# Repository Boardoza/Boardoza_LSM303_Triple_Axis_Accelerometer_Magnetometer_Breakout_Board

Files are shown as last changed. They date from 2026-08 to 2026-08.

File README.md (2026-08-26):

# Boardoza LSM303 Triple Axis Accelerometer & Magnetometer Breakout Board

The **Boardoza LSM303 Breakout Board** is a compact and ultra-low-power motion sensing solution featuring the **STMicroelectronics LSM303AGR** 6-axis e-compass sensor. It combines a **3-axis digital accelerometer** and a **3-axis digital magnetometer** in a single package, enabling accurate motion tracking, orientation sensing, and tilt-compensated compass applications.

Designed for seamless integration with both modern and legacy development platforms, the board includes a **TXS0104 bi-directional logic level shifter**, allowing direct compatibility with both **3.3V and 5V microcontrollers** such as ESP32, STM32, Raspberry Pi Pico, and Arduino Uno. With support for high-speed I<sup>2</sup>C communication and advanced interrupt functionality, this board is ideal for **robotics, wearable devices, navigation systems, drones, IoT applications, and smart motion-based projects**.

| Front Side | Back Side |
|:---:|:---:|
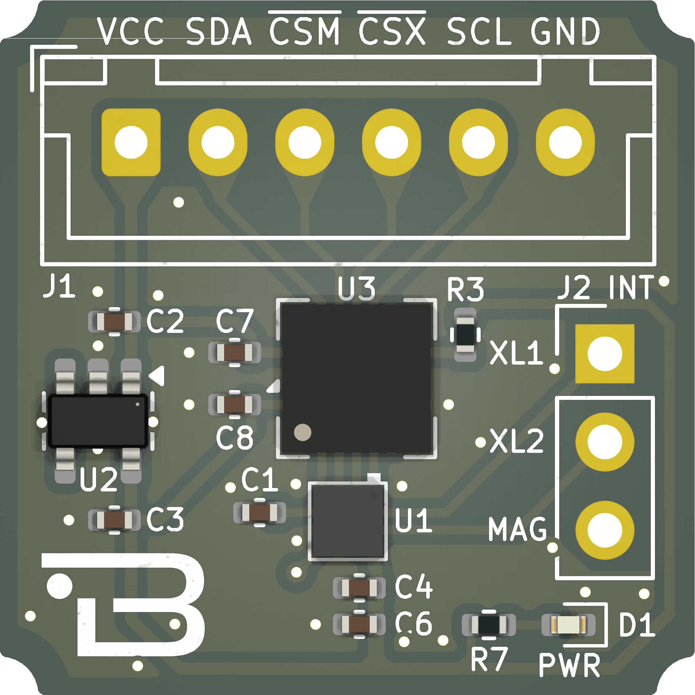
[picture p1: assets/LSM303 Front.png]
LSM303AGR Front
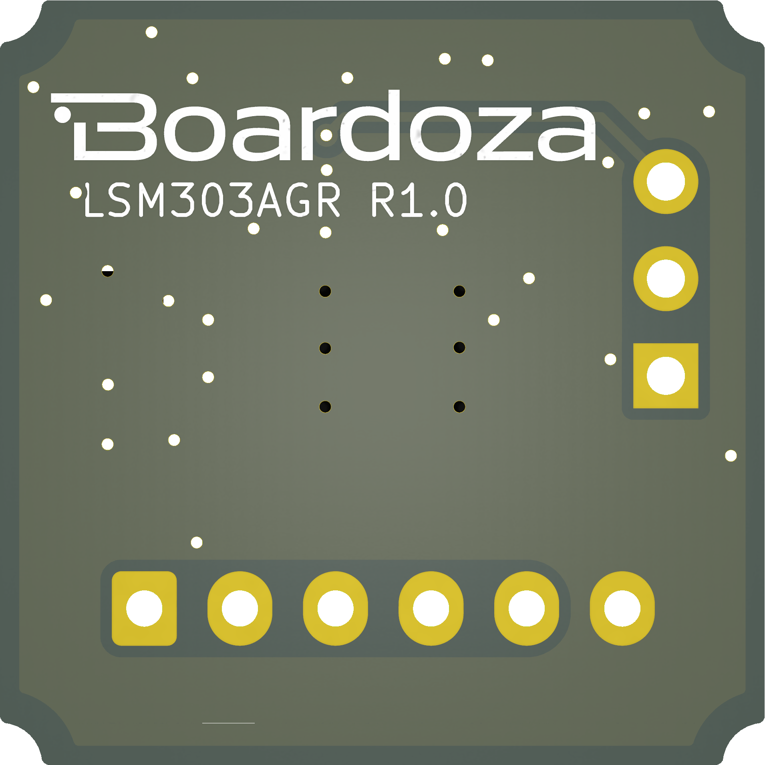
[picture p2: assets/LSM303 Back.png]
LSM303AGR Back
|  |  |

---

## Key Features

- **Integrated 6-Axis Motion Sensor:** Combines a 3-axis accelerometer and 3-axis magnetometer in a single compact module.
- **True E-Compass Functionality:** Enables accurate heading and orientation measurements using tilt compensation.
- **Wide Logic Compatibility:** Built-in TXS0104 level shifter supports both 3.3V and 5V systems.
- **High-Speed I<sup>2</sup>C Communication:** Supports Standard, Fast Mode (400kHz), and Fast Mode Plus (1MHz).
- **Ultra-Low Power Operation:** Optimized for battery-powered and energy-efficient embedded systems.
- **Programmable Interrupts:** Supports free-fall detection, orientation sensing, magnetic threshold detection, and motion events.

---

## Technical Specifications

**Model:** LSM303AGRTR  
**Manufacturer:** Boardoza    
**Manufacturer IC:** STMicroelectronics   
**Sensor Type:** 3-Axis Accelerometer + 3-Axis Magnetometer  
**Input Voltage:** 3.3 VDC - 5V DC  
**Voltage Logic Compatibility:** 3.3V / 5V (via TXS0104 Level Shifter)  
**Communication Interface:** I<sup>2</sup>C  / SPI  
**I<sup>2</sup>C Speed:** Standard Mode (100kHz), Fast Mode (400kHz), Fast Mode Plus (1MHz)   
**Accelerometer Full Scale Range:** ±2g / ±4g / ±8g / ±16g  
**Magnetic Field Range:** ±50 gauss  
**Accelerometer Resolution:** 12-bit  
**Magnetometer Resolution:** 16-bit  
**Functions:** Motion Detection, Orientation Sensing, Digital Compass, Tilt Compensation  
**Interrupt Features:** Free-fall, 6D/4D orientation, magnetic threshold interrupt  
**Operating Temperature:** -40°C to +85°C  
**Board Dimensions:** 20mm x 20mm  

---

## Board Pinout

### ( J1 ) Main Communication Connector

| Pin Number | Pin Name | Description |
|:---:|:---:|---|
| 1 | VCC | Voltage Supply Input |
| 2 | SDA / SDI / SDO | I<sup>2</sup>C Data / SPI Data Input / 3-wire SPI Data Output |
| 3 | /CS_MAG | Active-Low Magnetometer SPI Chip Select |
| 4 | /CS_XL | Active-Low Accelerometer SPI Chip Select |
| 5 | SCL / SPC | I<sup>2</sup>C Clock / SPI Clock |
| 6 | GND | Ground |

### ( J2 ) Interrupt Connector

| Pin Number | Pin Name | Description |
|:---:|:---:|---|
| 1 | XL1 | Accelerometer Interrupt Output 1 (3.3V Logic) |
| 2 | XL2 | Accelerometer Interrupt Output 2 (3.3V Logic) |
| 3 | MAG | Magnetometer Interrupt / Data Ready Output (3.3V Logic) |

---

## Board Dimensions

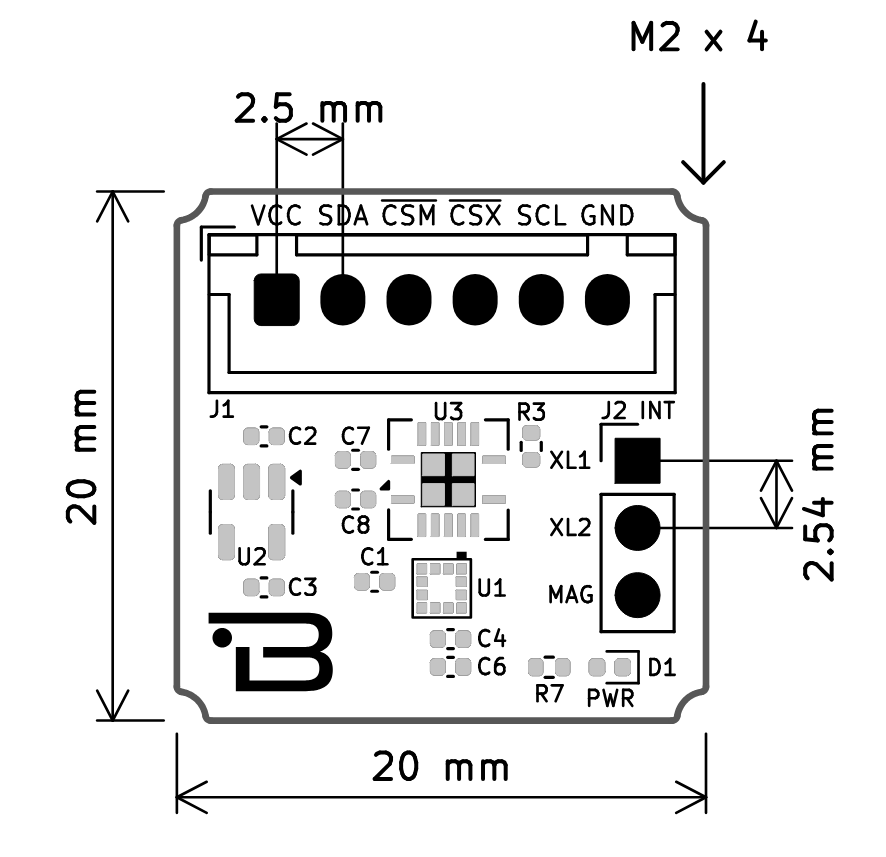
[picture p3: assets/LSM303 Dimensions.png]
LSM303AGRTR Dimensions


---

## Step Files

[Boardoza LSM303AGRTR.step](./assets/LSM303%20Step.step)

---

## Datasheet

[LSM303AGR Datasheet.pdf](./assets/LSM303%20Datasheet.pdf)

---

## Version History

- V1.0.0 - Initial Release

---

## Support

- If you have any questions or need support, please contact support@boardoza.com

---

## **License**

This repository contains both hardware and software components:

### **Hardware Design**

[][cc-by-sa]

All hardware design files are licensed under [Creative Commons Attribution-ShareAlike 4.0 International License][cc-by-sa].

[cc-by-sa]: http://creativecommons.org/licenses/by-sa/4.0/
[cc-by-sa-shield]: https://img.shields.io/badge/License-CC%20BY--SA%204.0-lightgrey.svg

### **Software/Firmware**

[][bsd]

All software and firmware are licensed under [BSD 3-Clause License][bsd].

[bsd]: https://opensource.org/licenses/BSD-3-Clause
[bsd-shield]: https://img.shields.io/badge/License-BSD%203--Clause-blue.svg

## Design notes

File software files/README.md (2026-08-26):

# Boardoza LSM303AGR Library





Ultra-compact 3D accelerometer and 3D magnetometer (eCompass) library for the STMicroelectronics **LSM303AGR** sensor.

## 🚀 Competitive Advantage

**First Arduino library with FULL I2C + SPI support for LSM303AGR!**

Unlike other LSM303AGR libraries that only support I2C, Boardoza provides:
- ✅ **Dual Protocol Support**: Choose I2C or SPI based on your application needs
- ✅ **25x Faster Data Transfer**: SPI operates at up to 10 MHz vs 400 kHz I2C Fast Mode
- ✅ **Unified API**: Same functions work regardless of I2C or SPI initialization
- ✅ **Flexible Integration**: Use I2C when pin count is limited, SPI when speed matters

## Features

- 🔄 **Dual Communication Protocol**: I2C and SPI (unique in Arduino ecosystem)
- 📊 **3-Axis Accelerometer**: ±2g to ±16g selectable range, 1-400Hz output data rate
- 🧭 **3-Axis Magnetometer**: ±50 gauss range, 10-100Hz output data rate
- 🌡️ **Temperature Sensor**: Integrated temperature measurement
- ⚡ **Power Management**: Low-power and high-resolution modes
- 🔍 **Built-in Self-Test**: Hardware verification for both accelerometer and magnetometer
- 🎯 **Calibration Support**: Example code for hard-iron and soft-iron compensation
- 📚 **4 Complete Examples**: I2C, SPI, calibration, and self-test

## Hardware Specifications

| Parameter | Value |
|---|---|
| Operating Voltage | 1.71V to 3.6V |
| Operating Temperature | -40°C to +85°C |
| Accelerometer Range | ±2g, ±4g, ±8g, ±16g (user-selectable) |
| Magnetometer Range | ±50 gauss |
| Accelerometer ODR | 1Hz to 400Hz |
| Magnetometer ODR | 10Hz to 100Hz |
| I2C Addresses | 0x19 (Accel), 0x1E (Mag) |
| SPI Mode | Mode 3 (CPOL=1, CPHA=1) |
| SPI Clock Speed | 1 MHz to 10 MHz |

## Installation

### Arduino IDE
1. Download this repository as ZIP
2. In Arduino IDE: **Sketch** → **Include Library** → **Add .ZIP Library**
3. Select the downloaded ZIP file
4. Restart Arduino IDE

### PlatformIO
```ini
lib_deps = 
    boardoza/Boardoza LSM303AGR@^1.0.0
```

## Quick Start

### I2C Mode (Simple)
```cpp
#include <Wire.h>
#include <LSM303AGR.h>

LSM303AGR sensor;

void setup() {
  Serial.begin(115200);
  Wire.begin();
  
  if (!sensor.begin()) {
    Serial.println("Sensor not found!");
    while (1);
  }
  
  sensor.setAccelRange(2);   // ±2g
  sensor.setMagMode(MAG_MODE_CONTINUOUS);
}

void loop() {
  float ax, ay, az, mx, my, mz;
  
  sensor.readAccel(ax, ay, az);  // m/s²
  sensor.readMag(mx, my, mz);    // µT
  
  Serial.print("Accel: "); 
  Serial.print(ax); Serial.print(", ");
  Serial.print(ay); Serial.print(", ");
  Serial.println(az);
  
  delay(100);
}
```

### SPI Mode (High-Speed)
```cpp
#include <SPI.h>
#include <LSM303AGR.h>

#define CS_ACCEL 10
#define CS_MAG   9

LSM303AGR sensor;

void setup() {
  Serial.begin(115200);
  SPI.begin();
  
  if (!sensor.beginSPI(CS_ACCEL, CS_MAG)) {
    Serial.println("Sensor not found!");
    while (1);
  }
  
  sensor.setSPIClockSpeed(10000000);  // 10 MHz for max speed
  sensor.setAccelRange(2);
  sensor.setAccelDataRate(400);       // 400Hz for high-speed logging
  sensor.setMagMode(MAG_MODE_CONTINUOUS);
}

void loop() {
  float ax, ay, az, mx, my, mz;
  
  if (sensor.isAccelDataReady()) {
    sensor.readAccel(ax, ay, az);
    // Process at 400Hz!
  }
  
  delay(10);
}
```

## Wiring

### I2C Wiring
```
LSM303AGR    Arduino Uno/Nano    Arduino Mega    ESP32
──────────────────────────────────────────────────────────
VDD          3.3V                3.3V            3.3V
GND          GND                 GND             GND
SDA          A4                  20              21 (GPIO21)
SCL          A5                  21              22 (GPIO22)
CS_ACCEL     3.3V (tied high)    3.3V            3.3V
CS_MAG       3.3V (tied high)    3.3V            3.3V
```

**Note**: I2C requires pull-up resistors (4.7kΩ recommended) on SDA and SCL lines.

### SPI Wiring
```
LSM303AGR    Arduino Uno/Nano    Arduino Mega    ESP32
──────────────────────────────────────────────────────────
VDD          3.3V                3.3V            3.3V
GND          GND                 GND             GND
MOSI         11                  51              23 (GPIO23)
MISO         12                  50              19 (GPIO19)
SCK          13                  52              18 (GPIO18)
CS_ACCEL     10 (user-defined)   10              5  (GPIO5)
CS_MAG       9  (user-defined)   9               4  (GPIO4)
SDA          N/C                 N/C             N/C
SCL          N/C                 N/C             N/C
```

**Note**: SPI requires separate chip select (CS) pins for accelerometer and magnetometer.

## I2C vs SPI Performance Comparison

| Feature | I2C | SPI |
|---|-----|-----|
| Max Clock Speed | 400 kHz (Fast Mode) | 10 MHz |
| Data Transfer Rate | ~50 KB/s | ~1.25 MB/s |
| Pin Count | 2 (SDA, SCL) | 5 (MOSI, MISO, SCK, CS_ACCEL, CS_MAG) |
| Multi-Device Bus | Yes (addressable) | No (requires separate CS pins) |
| Speed Advantage | Baseline (1x) | **25x faster** |
| Recommended Use | Low pin count, multiple sensors | High-speed logging, real-time control |

**Use I2C when:**
- Pin count is limited
- Sharing bus with other I2C devices
- Speed is not critical (<100Hz sampling)

**Use SPI when:**
- Maximum throughput is required (>100Hz)
- Real-time data logging applications
- Minimizing latency is critical
- Dedicated communication bus available

## API Reference

### Initialization
- `bool begin(TwoWire *wire = &Wire)` - Initialize in I2C mode
- `bool beginSPI(uint8_t csAccel, uint8_t csMag, SPIClass *spi = &SPI)` - Initialize in SPI mode
- `void setSPIClockSpeed(uint32_t speed)` - Set SPI clock (1-10 MHz)

### Accelerometer
- `bool setAccelRange(uint8_t range)` - Set range: 2, 4, 8, or 16 (±g)
- `bool setAccelDataRate(uint16_t rate)` - Set ODR: 1, 10, 25, 50, 100, 200, 400 (Hz)
- `bool enableAccelAxes(bool x, bool y, bool z)` - Enable/disable axes
- `bool setAccelPowerMode(LSM303AGR_PowerMode mode)` - Low-power or high-resolution
- `bool setAccelEnabled(bool enabled)` - Power up/down accelerometer
- `bool readAccel(float &x, float &y, float &z)` - Read acceleration (m/s²)
- `bool isAccelDataReady()` - Check if new data available

### Magnetometer
- `bool setMagMode(LSM303AGR_MagMode mode)` - Continuous, single-shot, or idle
- `bool setMagDataRate(uint16_t rate)` - Set ODR: 10, 20, 50, 100 (Hz)
- `bool setMagOffsetCancellation(bool enabled)` - Hard-iron compensation
- `bool readMag(float &x, float &y, float &z)` - Read magnetic field (µT)
- `bool isMagDataReady()` - Check if new data available

### Temperature
- `bool enableTemperature(bool enabled)` - Enable/disable temperature sensor
- `float readTemperature()` - Read temperature (°C, ±2°C accuracy)

### Self-Test
- `bool runAccelSelfTest()` - Verify accelerometer operation
- `bool runMagSelfTest()` - Verify magnetometer operation

### Protocol Query
- `bool isI2C()` - Check if initialized in I2C mode
- `bool isSPI()` - Check if initialized in SPI mode

## Examples

### 1. Basic_Reading_I2C
Simple I2C example reading accelerometer, magnetometer, and temperature.

### 2. Basic_Reading_SPI ⚡
High-speed SPI example demonstrating competitive advantage with 400Hz sampling.

### 3. Magnetometer_Calibration
Interactive calibration procedure for hard-iron and soft-iron compensation. Works with both I2C and SPI.

### 4. Self_Test
Hardware verification using built-in self-test features. Works with both I2C and SPI.

## Calibration

Magnetometer readings benefit from calibration to compensate for:
- **Hard-iron distortion**: Nearby ferromagnetic materials (e.g., screws, batteries)
- **Soft-iron distortion**: Induced magnetic fields from PCB traces, power circuits

Run the `Magnetometer_Calibration` example to obtain calibration coefficients. Apply in your code:

```cpp
// From calibration example
const float MAG_OFFSET_X = -12.34;
const float MAG_OFFSET_Y = 5.67;
const float MAG_OFFSET_Z = -8.90;
const float MAG_SCALE_X = 1.05;
const float MAG_SCALE_Y = 0.98;
const float MAG_SCALE_Z = 1.02;

float mx, my, mz;
sensor.readMag(mx, my, mz);

// Apply calibration
mx = (mx - MAG_OFFSET_X) * MAG_SCALE_X;
my = (my - MAG_OFFSET_Y) * MAG_SCALE_Y;
mz = (mz - MAG_OFFSET_Z) * MAG_SCALE_Z;
```

## Troubleshooting

**Sensor not detected (begin() returns false)**
- Check wiring connections
- Verify I2C addresses (0x19 for accelerometer, 0x1E for magnetometer)
- Ensure pull-up resistors on SDA/SCL (I2C mode)
- Check power supply (1.71V-3.6V)

**Erratic magnetometer readings**
- Move away from magnetic interference sources
- Run magnetometer calibration
- Enable offset cancellation: `sensor.setMagOffsetCancellation(true)`

**SPI communication failure**
- Verify CS pins are correctly connected and specified
- Check SPI mode (should be Mode 3)
- Ensure SPI clock speed is within 1-10 MHz range

**Self-test fails**
- Check for mechanical damage to sensor
- Verify electrical connections
- Try different sensor module
- Review self-test threshold criteria in example code

## License

This library is released under the MIT License. See LICENSE file for details.

## About Boardoza

Boardoza creates professional-grade Arduino libraries with a focus on:
- 🎯 **Complete Feature Coverage**: Full API implementation, not just basics
- 🚀 **Performance**: Advanced features like SPI support for maximum throughput
- 📖 **Documentation**: Comprehensive examples and clear API reference
- 🔧 **Professional Standards**: Follows industry best practices

Visit [Boardoza.com](https://boardoza.com) for more libraries and embedded solutions.

## Contributing

Contributions are welcome! Please:
1. Fork the repository
2. Create a feature branch
3. Follow the existing code style (Doxygen comments in .cpp only)
4. Test on hardware
5. Submit a pull request

## Support

- **Issues**: [GitHub Issues](https://github.com/Boardoza/Boardoza_LSM303AGR_Library/issues)
- **Email**: eray.eroglu@boardoza.com
- **Website**: [Boardoza.com](https://boardoza.com)

## Credits

Developed by Boardoza with reference to:
- STMicroelectronics LSM303AGR datasheet (DocID027765 Rev 3)
- STMicroelectronics application notes AN4602, AN4508

## Changelog

### Version 1.0.0 (Initial Release)
- ✅ Complete I2C implementation
- ✅ Complete SPI implementation (industry-first for LSM303AGR)
- ✅ Unified protocol-agnostic API
- ✅ Accelerometer with 4 ranges, 7 data rates
- ✅ Magnetometer with continuous/single-shot modes
- ✅ Temperature sensor support
- ✅ Built-in self-test routines
- ✅ 4 comprehensive examples
- ✅ Full Doxygen documentation

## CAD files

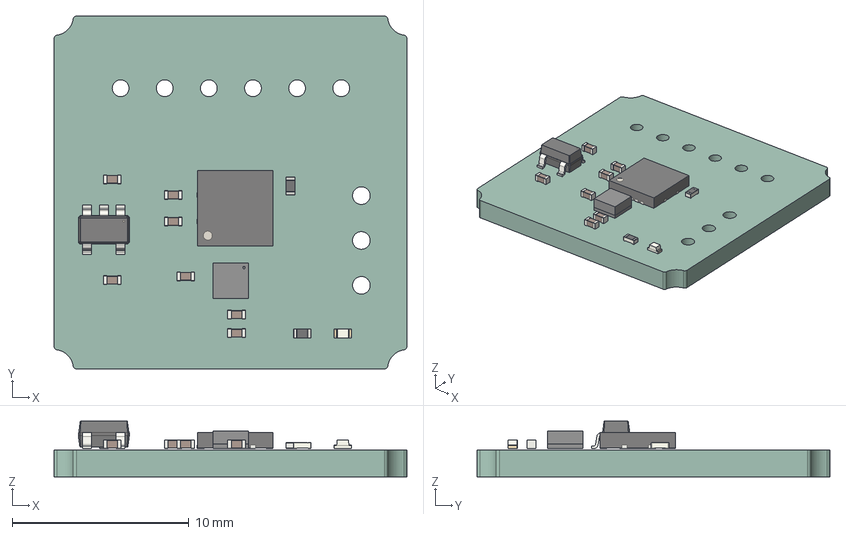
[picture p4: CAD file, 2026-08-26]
assets/LSM303 Step.step
20.0 x 20.0 x 3.15 mm
C_0402_1005Metric x 7
Texas_S-PVQFN-N14
LED_0402_1005Metric
R_0402_1005Metric x 2
kicad_embedded_3351D60FDAF86F74528C59DA770C054B
SOT-23-5
kibot_qq67svuy_PCB

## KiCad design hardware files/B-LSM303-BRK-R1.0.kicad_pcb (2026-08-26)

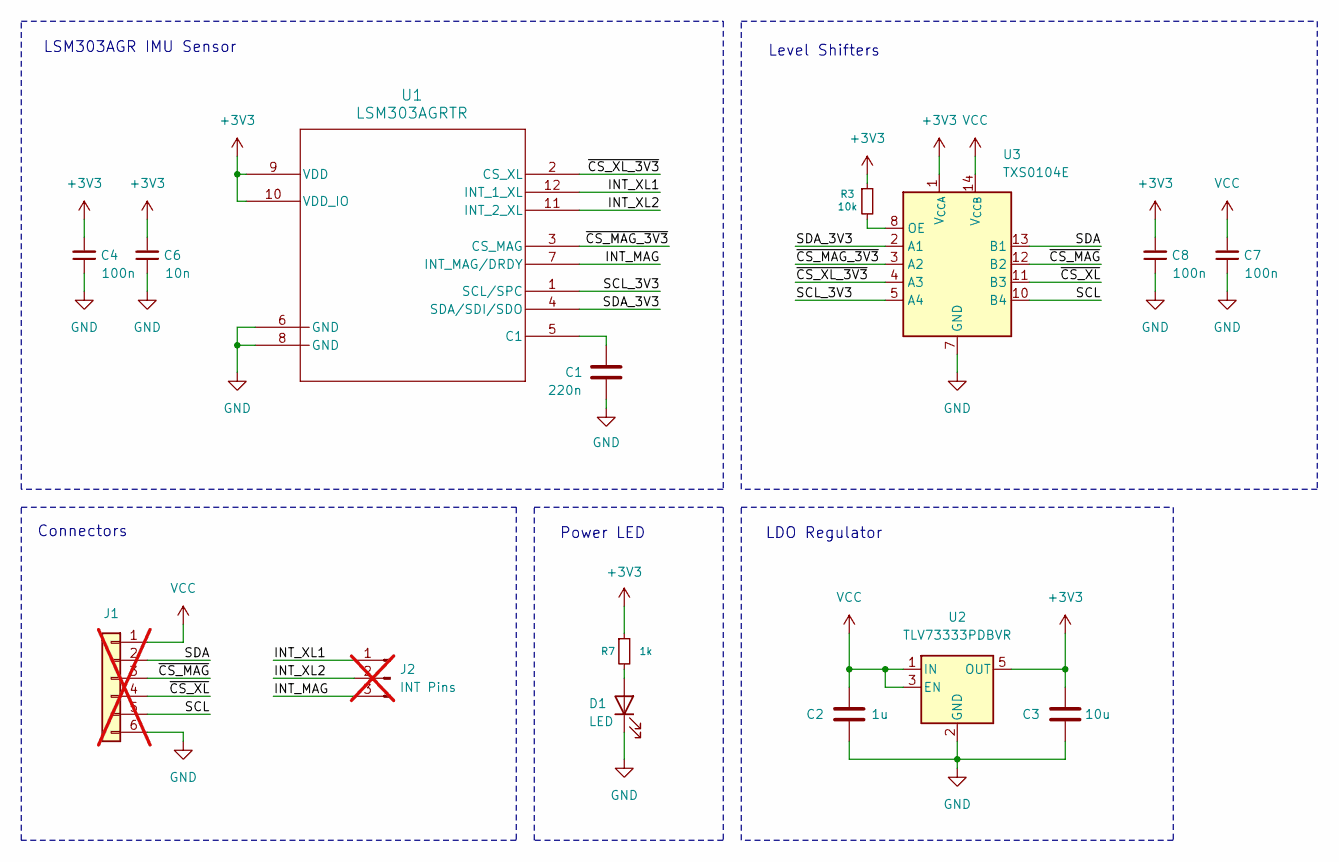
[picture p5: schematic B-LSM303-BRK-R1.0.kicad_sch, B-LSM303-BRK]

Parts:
C1: 220n; C_0402_1005Metric; MPN MCF02KTX100224
C2: 1u; C_0402_1005Metric; MPN CL05A105KO5NNNC
C3: 10u; C_0402_1005Metric; MPN CL05A106MP5NUNC
C4, C7, C8: 100n; C_0402_1005Metric; MPN CL05B104KO5NNNC
C6: 10n; C_0402_1005Metric; MPN CL05B103KA5NNNC
D1: LED; LED_0402_1005Metric; MPN 16-213SURC/S530-A3/TR8
J1: Conn_01x06; JST_XH_B6B-XH-A_1x06_P2.50mm_Vertical; MPN L-KLS1-2.50-06-SB; not fitted
J2: INT Pins; PinHeader_1x03_P2.54mm_Vertical; MPN L-KLS1-207-1-03-S; not fitted
R3: 10k; R_0402_1005Metric; MPN CRT02J6E1002
R7: 1k; R_0402_1005Metric; MPN 0402WGJ0102TCE
U1: LSM303AGRTR; SON_03AGRTR_STM; MPN LSM303AGRTR
U2: TLV73333PDBVR; SOT-23-5; MPN TLV73333PDBVR
U3: TXS0104E; Texas_S-PVQFN-N14; MPN TXS0104ERGYR

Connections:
+3V3: C3.1, C4.2, C6.2, C8.2, R3.1, R7.1, U1.9 (VDD), U1.10 (VDD_IO), U2.5 (OUT), U3.1 (V_{CCA})
/INT_MAG: J2.3, U1.7 (INT_MAG/DRDY)
/INT_XL1: J2.1, U1.12 (INT_1_XL)
/INT_XL2: J2.2, U1.11 (INT_2_XL)
/SCL: J1.5, U3.10 (B4)
/SCL_3V3: U1.1 (SCL/SPC), U3.5 (A4)
/SDA: J1.2, U3.13 (B1)
/SDA_3V3: U1.4 (SDA/SDI/SDO), U3.2 (A1)
/~CS_MAG_3V3: U1.3 (CS_MAG), U3.3 (A2)
/~CS_MAG: J1.3, U3.12 (B2)
/~CS_XL_3V3: U1.2 (CS_XL), U3.4 (A3)
/~CS_XL: J1.4, U3.11 (B3)
GND: C1.1, C2.1, C3.2, C4.1, C6.1, C7.1, C8.1, D1.1 (K), J1.6, U1.6 (GND), U1.8 (GND), U2.2 (GND), U3.7 (GND), U3.15
unnamed: D1.2 (A), R7.2
unnamed: C1.2, U1.5 (C1)
unnamed: R3.2, U3.8 (OE)
VCC: C2.2, C7.2, J1.1, U2.1 (IN), U2.3 (EN), U3.14 (V_{CCB})

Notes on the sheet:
Connectors
LDO Regulator
Power LED
LSM303AGR IMU Sensor
Level Shifters

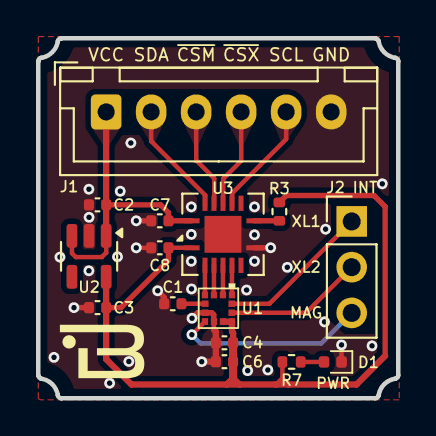
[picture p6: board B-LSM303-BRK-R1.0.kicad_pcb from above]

Board: 2 copper layers, 20.0 x 20.0 mm, 15 parts (0 on the bottom side), 17 nets.

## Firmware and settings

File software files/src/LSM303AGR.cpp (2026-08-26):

#include "LSM303AGR.h"

/**
 * @brief Constructor for LSM303AGR class
 * 
 * Initializes member variables to default values. The sensor is not configured
 * until begin() or beginSPI() is called.
 */
LSM303AGR::LSM303AGR() {
  _wire = nullptr;
  _spi = nullptr;
  _csAccel = 0;
  _csMag = 0;
  _spiSpeed = 1000000; // 1 MHz default
  _protocol = PROTOCOL_I2C;
  _accelRange = 2;
  _accelScale = 1.0f;
}

/**
 * @brief Initialize the LSM303AGR sensor in I2C mode
 * 
 * This method configures the sensor for I2C communication, verifies both
 * accelerometer and magnetometer are present via WHO_AM_I register checks,
 * and applies default configuration settings.
 * 
 * Default configuration:
 * - Accelerometer: ±2g range, 10Hz ODR, high-resolution mode, all axes enabled
 * - Magnetometer: Continuous mode, 10Hz ODR, offset cancellation off
 * 
 * @param wire Pointer to TwoWire object for I2C communication (default: &Wire)
 * @return true if both sensors detected and configured successfully, false otherwise
 */
bool LSM303AGR::begin(TwoWire* wire) {
  _wire = wire;
  _protocol = PROTOCOL_I2C;
  
  _wire->begin();
  
  // Verify accelerometer WHO_AM_I
  uint8_t whoAmIA = readAccelRegI2C(LSM303AGR_WHO_AM_I_A);
  if (whoAmIA != LSM303AGR_WHO_AM_I_A_VALUE) {
    return false;
  }
  
  // Verify magnetometer WHO_AM_I
  uint8_t whoAmIM = readMagRegI2C(LSM303AGR_WHO_AM_I_M);
  if (whoAmIM != LSM303AGR_WHO_AM_I_M_VALUE) {
    return false;
  }
  
  // Configure accelerometer: 10Hz ODR, high-resolution mode, all axes enabled
  writeAccelRegI2C(LSM303AGR_CTRL_REG1_A, 0x27); // ODR=10Hz (0010), all axes enabled (0111)
  writeAccelRegI2C(LSM303AGR_CTRL_REG4_A, 0x08); // High-resolution mode, ±2g range
  
  _accelRange = 2;
  updateAccelScale();
  
  // Configure magnetometer: Continuous mode, 10Hz ODR
  writeMagRegI2C(LSM303AGR_CFG_REG_A_M, 0x00); // Continuous mode, 10Hz
  writeMagRegI2C(LSM303AGR_CFG_REG_B_M, 0x00); // Offset cancellation off
  writeMagRegI2C(LSM303AGR_CFG_REG_C_M, 0x00); // Continuous mode enable
  
  return true;
}

/**
 * @brief Update accelerometer scale factor based on current range setting
 * 
 * This internal method calculates the conversion factor from LSB to m/s²
 * based on the configured full-scale range.
 */
void LSM303AGR::updateAccelScale() {
  // LSM303AGR sensitivity in mg/LSB for different ranges in high-resolution mode
  // ±2g: ~1 mg/LSB, ±4g: ~2 mg/LSB, ±8g: ~4 mg/LSB, ±16g: ~12 mg/LSB
  float mgPerLSB;
  switch (_accelRange) {
    case 2:  mgPerLSB = 1.0f; break;
    case 4:  mgPerLSB = 2.0f; break;
    case 8:  mgPerLSB = 4.0f; break;
    case 16: mgPerLSB = 12.0f; break;
    default: mgPerLSB = 1.0f;
  }
  // Convert mg/LSB to m/s² per LSB: (mg/LSB) * (g/1000mg) * (9.80665 m/s² per g)
  _accelScale = mgPerLSB * 0.00980665f;
}

// ========== I2C Register Access Helpers ==========

/**
 * @brief Write a byte to an accelerometer register via I2C
 * 
 * @param reg Register address
 * @param value Value to write
 */
void LSM303AGR::writeAccelRegI2C(uint8_t reg, uint8_t value) {
  _wire->beginTransmission(LSM303AGR_ACCEL_ADDRESS);
  _wire->write(reg);
  _wire->write(value);
  _wire->endTransmission();
}

/**
 * @brief Read a byte from an accelerometer register via I2C
 * 
 * @param reg Register address
 * @return Value read from register
 */
uint8_t LSM303AGR::readAccelRegI2C(uint8_t reg) {
  _wire->beginTransmission(LSM303AGR_ACCEL_ADDRESS);
  _wire->write(reg);
  _wire->endTransmission(false);
  _wire->requestFrom(LSM303AGR_ACCEL_ADDRESS, (uint8_t)1);
  return _wire->read();
}

/**
 * @brief Write a byte to a magnetometer register via I2C
 * 
 * @param reg Register address
 * @param value Value to write
 */
void LSM303AGR::writeMagRegI2C(uint8_t reg, uint8_t value) {
  _wire->beginTransmission(LSM303AGR_MAG_ADDRESS);
  _wire->write(reg);
  _wire->write(value);
  _wire->endTransmission();
}

/**
 * @brief Read a byte from a magnetometer register via I2C
 * 
 * @param reg Register address
 * @return Value read from register
 */
uint8_t LSM303AGR::readMagRegI2C(uint8_t reg) {
  _wire->beginTransmission(LSM303AGR_MAG_ADDRESS);
  _wire->write(reg);
  _wire->endTransmission(false);
  _wire->requestFrom(LSM303AGR_MAG_ADDRESS, (uint8_t)1);
  return _wire->read();
}

/**
 * @brief Read multiple bytes from consecutive registers via I2C
 * 
 * This method uses I2C auto-increment to efficiently read multiple consecutive
 * registers in a single transaction.
 * 
 * @param address I2C device address
 * @param reg Starting register address
 * @param buffer Buffer to store read data
 * @param length Number of bytes to read
 */
void LSM303AGR::readMultiI2C(uint8_t address, uint8_t reg, uint8_t* buffer, uint8_t length) {
  _wire->beginTransmission(address);
  _wire->write(reg | 0x80); // Set auto-increment bit
  _wire->endTransmission(false);
  _wire->requestFrom(address, length);
  for (uint8_t i = 0; i < length; i++) {
    buffer[i] = _wire->read();
  }
}

/**
 * @brief Check if communication protocol is I2C
 * 
 * @return true if using I2C, false if using SPI
 */
bool LSM303AGR::isI2C() {
  return _protocol == PROTOCOL_I2C;
}

/**
 * @brief Check if communication protocol is SPI
 * 
 * @return true if using SPI, false if using I2C
 */
bool LSM303AGR::isSPI() {
  return _protocol == PROTOCOL_SPI;
}

// ========== SPI Initialization ==========
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

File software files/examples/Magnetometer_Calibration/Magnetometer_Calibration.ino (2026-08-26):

/**
 * Magnetometer_Calibration Example
 * 
 * Guides you through magnetometer calibration to compensate for hard-iron and soft-iron
 * distortions. These distortions are caused by nearby ferromagnetic materials (hard-iron)
 * and induced magnetic fields (soft-iron).
 * 
 * This example works with BOTH I2C and SPI modes - uncomment your preferred mode below.
 * 
 * Calibration Procedure:
 * 1. Upload this sketch
 * 2. Open Serial Monitor (115200 baud)
 * 3. When prompted, slowly rotate the sensor in all directions (figure-8 pattern)
 * 4. Continue for 30 seconds until data collection completes
 * 5. Calibration values will be displayed - save these for your application
 * 
 * Hardware Setup:
 * - See Basic_Reading_I2C or Basic_Reading_SPI examples for wiring
 */

#include <LSM303AGR.h>

// ===== CONFIGURATION: Choose communication mode =====
#define USE_I2C  // Comment this line and uncomment USE_SPI for SPI mode
// #define USE_SPI

#ifdef USE_SPI
  #include <SPI.h>
  #define CS_ACCEL 10
  #define CS_MAG   9
#else
  #include <Wire.h>
#endif

LSM303AGR sensor;

// Calibration data
float magXMin = 9999, magXMax = -9999;
float magYMin = 9999, magYMax = -9999;
float magZMin = 9999, magZMax = -9999;

void setup() {
  Serial.begin(115200);
  while (!Serial);
  
  Serial.println("Boardoza LSM303AGR - Magnetometer Calibration");
  Serial.println("===============================================");
  
#ifdef USE_SPI
  SPI.begin();
  if (!sensor.beginSPI(CS_ACCEL, CS_MAG)) {
#else
  Wire.begin();
  if (!sensor.begin()) {
#endif
    Serial.println("ERROR: Sensor not detected!");
    while (1) delay(10);
  }
  
#ifdef USE_SPI
  Serial.println("Mode: SPI");
#else
  Serial.println("Mode: I2C");
#endif
  
  // Configure magnetometer
  sensor.setMagMode(MAG_MODE_CONTINUOUS);
  sensor.setMagDataRate(50); // 50Hz for calibration
  sensor.setMagOffsetCancellation(false); // Disable internal compensation during calibration
  
  Serial.println();
  Serial.println("===========================================");
  Serial.println(" CALIBRATION PROCEDURE");
  Serial.println("===========================================");
  Serial.println("1. Slowly rotate the sensor in ALL directions");
  Serial.println("2. Make figure-8 patterns in the air");
  Serial.println("3. Ensure full 3D rotation coverage");
  Serial.println("4. Continue for 30 seconds");
  Serial.println();
  Serial.println("Starting in 3 seconds...");
  delay(3000);
  
  Serial.println("START ROTATING NOW!");
  Serial.println();
}

void loop() {
  static unsigned long startTime = millis();
  static unsigned long lastPrint = 0;
  static int sampleCount = 0;
  
  unsigned long elapsed = millis() - startTime;
  
  // Collect data for 30 seconds
  if (elapsed < 30000) {
    float magX, magY, magZ;
    
    if (sensor.isMagDataReady()) {
      sensor.readMag(magX, magY, magZ);
      
      // Update min/max values
      if (magX < magXMin) magXMin = magX;
      if (magX > magXMax) magXMax = magX;
      if (magY < magYMin) magYMin = magY;
      if (magY > magYMax) magYMax = magY;
      if (magZ < magZMin) magZMin = magZ;
      if (magZ > magZMax) magZMax = magZ;
      
      sampleCount++;
      
      // Print progress every second
      if (millis() - lastPrint >= 1000) {
        lastPrint = millis();
        int secondsRemaining = (30000 - elapsed) / 1000;
        Serial.print("Collecting... ");
        Serial.print(sampleCount);
        Serial.print(" samples  |  ");
        Serial.print(secondsRemaining);
        Serial.println(" seconds remaining");
      }
    }
  } else {
    // Calibration complete - calculate and display results
    Serial.println();
    Serial.println("===========================================");
    Serial.println(" CALIBRATION COMPLETE!");
    Serial.println("===========================================");
    Serial.print("Total samples collected: ");
    Serial.println(sampleCount);
    Serial.println();
    
    // Calculate hard-iron offsets (mid-point between min and max)
    float offsetX = (magXMax + magXMin) / 2.0f;
    float offsetY = (magYMax + magYMin) / 2.0f;
    float offsetZ = (magZMax + magZMin) / 2.0f;
    
    // Calculate soft-iron scale factors (range for each axis)
    float rangeX = magXMax - magXMin;
    float rangeY = magYMax - magYMin;
    float rangeZ = magZMax - magZMin;
    float avgRange = (rangeX + rangeY + rangeZ) / 3.0f;
    
    float scaleX = avgRange / rangeX;
    float scaleY = avgRange / rangeY;
    float scaleZ = avgRange / rangeZ;
    
    // Display raw min/max
    Serial.println("Raw Magnetometer Ranges:");
    Serial.print("  X: "); Serial.print(magXMin, 1); Serial.print(" to "); Serial.print(magXMax, 1); Serial.println(" µT");
    Serial.print("  Y: "); Serial.print(magYMin, 1); Serial.print(" to "); Serial.print(magYMax, 1); Serial.println(" µT");
    Serial.print("  Z: "); Serial.print(magZMin, 1); Serial.print(" to "); Serial.print(magZMax, 1); Serial.println(" µT");
    Serial.println();
    
    // Display calibration values
    Serial.println("🎯 CALIBRATION VALUES (copy these to your code):");
    Serial.println("------------------------------------------------");
    Serial.print("const float MAG_OFFSET_X = "); Serial.print(offsetX, 2); Serial.println(";");
    Serial.print("const float MAG_OFFSET_Y = "); Serial.print(offsetY, 2); Serial.println(";");
    Serial.print("const float MAG_OFFSET_Z = "); Serial.print(offsetZ, 2); Serial.println(";");
    Serial.println();
    Serial.print("const float MAG_SCALE_X = "); Serial.print(scaleX, 4); Serial.println(";");
    Serial.print("const float MAG_SCALE_Y = "); Serial.print(scaleY, 4); Serial.println(";");
    Serial.print("const float MAG_SCALE_Z = "); Serial.print(scaleZ, 4); Serial.println(";");
    Serial.println("------------------------------------------------");
    Serial.println();
    
    Serial.println("How to use in your code:");
    Serial.println("  float magX, magY, magZ;");
    Serial.println("  sensor.readMag(magX, magY, magZ);");
    Serial.println("  ");
    Serial.println("  // Apply calibration");
    Serial.println("  magX = (magX - MAG_OFFSET_X) * MAG_SCALE_X;");
    Serial.println("  magY = (magY - MAG_OFFSET_Y) * MAG_SCALE_Y;");
    Serial.println("  magZ = (magZ - MAG_OFFSET_Z) * MAG_SCALE_Z;");
    Serial.println();
    
    // Demonstrate calibrated readings
    Serial.println("Showing calibrated readings (press reset to recalibrate):");
    Serial.println();
    
    while (1) {
      float magX, magY, magZ;
      if (sensor.isMagDataReady()) {
        sensor.readMag(magX, magY, magZ);
        
        // Apply calibration
        magX = (magX - offsetX) * scaleX;
        magY = (magY - offsetY) * scaleY;
        magZ = (magZ - offsetZ) * scaleZ;
        
        // Calculate heading (0-360 degrees)
        float heading = atan2(magY, magX) * 180.0f / PI;
        if (heading < 0) heading += 360;
        
        Serial.print("Calibrated: X=");
        Serial.print(magX, 1);
        Serial.print(" Y=");
        Serial.print(magY, 1);
        Serial.print(" Z=");
        Serial.print(magZ, 1);
        Serial.print(" µT  |  Heading: ");
        Serial.print(heading, 1);
        Serial.println("°");
        
        delay(200);
      }
    }
  }
}

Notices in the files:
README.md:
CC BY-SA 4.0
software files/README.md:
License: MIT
